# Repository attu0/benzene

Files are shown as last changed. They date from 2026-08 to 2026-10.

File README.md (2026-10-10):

<div align="center">

# 🤖 Benzene
### An Autonomous Differential-Drive Mobile Robot

**A ROS 2-based autonomous mobile robot developed at Rajarambapu Institute of Technology (RIT), with support from Taikisha Engineering India Ltd.**

Benzene Autonomous Mobile Robot

<p>
  <a href="https://github.com/attu0/benzene">📦 GitHub Repository</a> •
  <a href="https://drive.google.com/file/d/1qdtDz3HJxDPnA_4TYmKJY9449RnS3Dy-/view?usp=sharing">🎥 Robot Demonstration</a>
</p>

</div>

---

## 📌 Table of Contents

- [🤖 About the Project](#-about-the-project)
- [✨ Key Features](#-key-features)
- [🛠️ CAD Design and Physical Robot](#️-cad-design-and-physical-robot)
- [🏗️ System Architecture](#️-system-architecture)
- [🔌 Hardware Components](#-hardware-components)
- [📐 Circuit and Deployment Diagrams](#-circuit-and-deployment-diagrams)
- [💻 Software Stack](#-software-stack)
- [📦 ROS 2 Packages](#-ros-2-packages)
- [⚙️ Installation and Setup](#️-installation-and-setup)
- [🔨 Build the Workspace](#-build-the-workspace)
- [🌎 Run the Simulation](#-run-the-simulation)
- [🗺️ SLAM and Autonomous Navigation](#️-slam-and-autonomous-navigation)
- [🤖 Run on the Physical Robot](#-run-on-the-physical-robot)
- [📁 Repository Structure](#-repository-structure)
- [🚀 Future Improvements](#-future-improvements)
- [👥 Team and Acknowledgements](#-team-and-acknowledgements)
- [🤝 Contributing](#-contributing)
- [📄 License](#-license)

---

## 🤖 About the Project

**Benzene** is an autonomous differential-drive mobile robot developed as a final-year engineering project at **Rajarambapu Institute of Technology (RIT), Rajaramnagar**, with support from **Taikisha Engineering India Ltd.**

The project combines mechanical design, embedded systems, sensor integration, and robotics software to develop a mobile platform capable of navigating its environment.

The software architecture uses ROS 2 to connect robot hardware, sensor drivers, motion control, localisation, mapping, and navigation components. Gazebo and RViz2 support simulation, visualisation, and testing during development.

### 📋 Project Overview

| Specification | Details |
|---|---|
| **Robot Type** | Differential-drive mobile robot |
| **Robotics Middleware** | ROS 2 Jazzy |
| **Operating System** | Ubuntu 24.04 LTS |
| **Robot Modelling** | URDF / Xacro |
| **Simulation** | Gazebo |
| **Visualisation** | RViz2 |
| **Mapping** | SLAM Toolbox |
| **Navigation** | Nav2 |
| **Repository** | [attu0/benzene](https://github.com/attu0/benzene) |

---

## ✨ Key Features

- **Differential-Drive Control** — Independent left and right wheel control for forward, reverse, and turning motion.
- **ROS 2 Architecture** — Modular packages for robot description, control, hardware, sensors, and navigation.
- **Robot Modelling** — URDF/Xacro-based robot description for visualisation and simulation.
- **Gazebo Simulation** — Test robot behaviour in virtual environments.
- **SLAM** — Map an environment while estimating the robot's position.
- **Autonomous Navigation** — Nav2-based path planning and goal-directed navigation.
- **Sensor Integration** — Interfaces for LiDAR, IMU, camera, and ultrasonic sensing, depending on the active configuration.
- **Hardware Integration** — Communication between the onboard computer, embedded controller, and drive system.

> **Note:** Feature availability depends on the hardware, packages, launch files, and configuration in the current repository branch.

---

## 🛠️ CAD Design and Physical Robot

The robot chassis was designed to provide a compact platform for the drive system, onboard computer, sensors, and power electronics.

### 🧩 CAD Model

<p align="center">
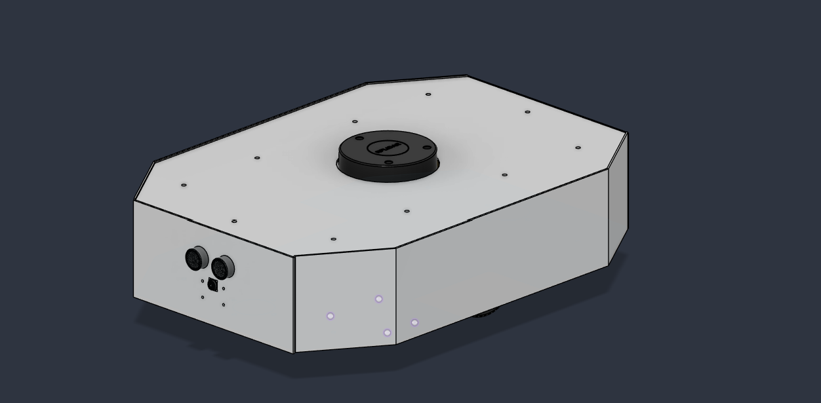
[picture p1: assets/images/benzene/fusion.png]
Benzene CAD model designed in Fusion 360
  
</p>

<p align="center"><em>CAD model of the Benzene mobile robot.</em></p>

### 🤖 Physical Prototype

<p align="center">
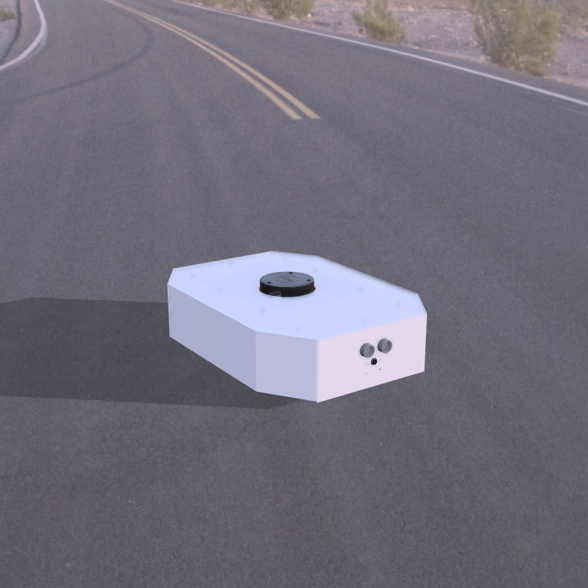
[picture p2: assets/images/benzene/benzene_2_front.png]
Benzene robot render
  
</p>

<p align="center"><em>Rendered view of the Benzene mobile robot.</em></p>

🎥 **[Watch the Robot Demonstration](https://drive.google.com/file/d/1qdtDz3HJxDPnA_4TYmKJY9449RnS3Dy-/view?usp=sharing)**

---

## 🏗️ System Architecture

The system architecture connects the sensing, control, localisation, and navigation components through ROS 2.

```text
                 ┌───────────────────────────┐
                 │         ROS 2 Jazzy       │
                 │    Robotics Middleware    │
                 └─────────────┬─────────────┘
                               │
              ┌────────────────┼────────────────┐
              │                │                │
              ▼                ▼                ▼
       ┌─────────────┐  ┌─────────────┐  ┌─────────────┐
       │   Control   │  │ Localisation│  │ Navigation  │
       │ Motor Cmds  │  │  Odometry   │  │    Nav2     │
       └──────┬──────┘  └──────▲──────┘  └──────┬──────┘
              │                │                │
              ▼                │                ▼
       ┌─────────────────────────────────────────────┐
       │                Robot Hardware               │
       │ Motors │ Encoders │ IMU │ LiDAR │ Sensors  │
       └─────────────────────────────────────────────┘
```

### Operating Modes

| Mode | Description |
|---|---|
| **Simulation** | Robot model and simulated environment run in Gazebo. |
| **Physical Robot** | ROS 2 communicates with the robot hardware through the configured hardware interfaces. |

> The architecture is a conceptual overview. Actual nodes, topics, transforms, and interfaces depend on the launch configuration.

---

## 🔌 Hardware Components

The robot integrates mechanical, electrical, and computing components to support mobile robotics development.

| Subsystem | Component |
|---|---|
| Mobile Base | Differential-drive chassis |
| Main Computer | Raspberry Pi |
| Microcontroller | Arduino Uno R3 |
| Drive System | Geared DC motors |
| Motor Control | Dual-channel motor driver |
| Feedback | Wheel encoders, where configured |
| Range Sensing | 2D LiDAR |
| Inertial Sensing | IMU |
| Proximity Sensing | Ultrasonic sensor |
| Power System | Battery and regulated DC supply |
| Mechanical Structure | Designed and fabricated chassis |

*Verify the actual component models, pin assignments, and electrical connections against the current hardware revision before assembly or operation.*

---

## 📐 Circuit and Deployment Diagrams

### 🔋 Electrical Circuit Diagram

<p align="center">
  Benzene electrical circuit and wiring diagram
</p>

The circuit diagram illustrates the electrical connections between the power supply, voltage regulation, motor driver, microcontroller, onboard computer, and sensors.

### 🖥️ Hardware Deployment Diagram

<p align="center">
  Benzene hardware deployment diagram
</p>

The deployment diagram provides a view of the robot's internal hardware layout and component placement.

---

## 💻 Software Stack

| Technology | Purpose |
|---|---|
| **ROS 2 Jazzy** | Robotics middleware |
| **Ubuntu 24.04 LTS** | Development operating system |
| **URDF / Xacro** | Robot description |
| **Gazebo** | Simulation |
| **RViz2** | Robot and sensor visualisation |
| **ros2_control** | Hardware and motion control, where configured |
| **EKF** | Sensor fusion and state estimation, where configured |
| **SLAM Toolbox** | Mapping |
| **Nav2** | Autonomous navigation |
| **colcon** | Workspace build system |
| **rosdep** | Dependency management |

---

## 📦 ROS 2 Packages

The repository follows a modular package structure.

| Package | Purpose |
|---|---|
| `benzene_arduino` | Embedded controller code and hardware testing |
| `benzene_bringup` | Robot launch files and startup configuration |
| `benzene_camera` | Camera integration |
| `benzene_control` | Controller configuration |
| `benzene_dagger` | Behavioural cloning and imitation learning |
| `benzene_description` | URDF/Xacro and robot model resources |
| `benzene_docking` | Docking-related functionality |
| `benzene_explore` | Autonomous exploration |
| `benzene_explore_msgs` | Exploration-related interfaces |
| `benzene_gazebo` | Simulation worlds, models, and launch files |
| `benzene_hardware` | Hardware interfaces |
| `benzene_imu` | IMU integration |
| `benzene_localization` | Localisation and sensor fusion |
| `benzene_msgs` | Custom ROS 2 interfaces |
| `benzene_navigation` | SLAM, Nav2, maps, and navigation configuration |
| `benzene_serial` | Serial communication |
| `benzene_system_tests` | System-level testing |
| `benzene_ultrasonic` | Ultrasonic sensor integration |
| `docker` | Docker configuration |

---

## ⚙️ Installation and Setup

### Requirements

**Software**
- Ubuntu 24.04 LTS
- ROS 2 Jazzy
- Git
- `colcon`
- `rosdep`
- Gazebo and RViz2
- Nav2 and SLAM Toolbox for the configured navigation workflow

### 1. Create a Colcon Workspace

```bash
mkdir -p ~/ros2_ws/src
cd ~/ros2_ws/src
```

### 2. Clone the Repository

```bash
git clone https://github.com/attu0/benzene.git
cd benzene
```

### 3. Install Build and Dependency Tools

Install ROS 2 Jazzy by following the [official installation guide](https://docs.ros.org/en/jazzy/Installation/Ubuntu-Install-Debs.html).

```bash
sudo apt update
sudo apt install python3-rosdep python3-colcon-common-extensions
```

Initialise `rosdep` if it has not already been initialised:

```bash
sudo rosdep init
rosdep update
```

If `rosdep` is already initialised, run only:

```bash
rosdep update
```

### 4. Install Repository Dependencies

```bash
cd ~/ros2_ws
source /opt/ros/jazzy/setup.bash

rosdep install \
  --from-paths src \
  --ignore-src \
  --rosdistro jazzy \
  -r -y
```

---

## 🔨 Build the Workspace

Navigate to the workspace root and build the packages:

```bash
cd ~/ros2_ws
source /opt/ros/jazzy/setup.bash
colcon build --symlink-install
```

To build a specific package and its dependencies:

```bash
colcon build --symlink-install --packages-up-to benzene_bringup
```

### Source the Workspace

After a successful build:

```bash
source ~/ros2_ws/install/setup.bash
```

### Automatically Source ROS 2 Using `.bashrc`

To automatically source ROS 2 and your workspace in new terminals, add the following lines to `~/.bashrc`:

```bash
# ROS 2 Jazzy
source /opt/ros/jazzy/setup.bash

# Benzene workspace
source ~/ros2_ws/install/setup.bash
```

Reload the configuration:

```bash
source ~/.bashrc
```

Verify that the packages are discoverable:

```bash
ros2 pkg list | grep benzene
```

---

## 🌎 Run the Simulation

Benzene includes Gazebo simulation resources for testing the robot in virtual environments.

### 1. Source the Environment

```bash
source /opt/ros/jazzy/setup.bash
source ~/ros2_ws/install/setup.bash
```

### 2. Launch Gazebo

The following example launches the robot in a warehouse environment:

```bash
ros2 launch benzene_gazebo benzene.gazebo.launch.py \
  enable_odom_tf:=true \
  headless:=False \
  load_controllers:=true \
  world_file:=warehouse.sdf \
  use_rviz:=true \
  use_robot_state_pub:=true \
  use_sim_time:=true \
  x:=0.0 y:=0.0 z:=0.20 \
  roll:=0.0 pitch:=0.0 yaw:=0.0
```

> **Note:** Launch arguments and world filenames may vary between branches. Check the launch file's supported arguments if the command does not match your current setup.

---

## 🗺️ SLAM and Autonomous Navigation

Benzene uses **SLAM Toolbox** and **Nav2** in the configured mapping and navigation workflow.

### Launch Navigation in Simulation

```bash
ros2 launch benzene_bringup benzene_navigation.launch.py \
  enable_odom_tf:=false \
  headless:=False \
  load_controllers:=true \
  slam:=True \
  use_rviz:=true \
  use_robot_state_pub:=true \
  use_sim_time:=true \
  x:=0.0 y:=0.0 z:=0.20 \
  roll:=0.0 pitch:=0.0 yaw:=0.0 \
  world_file:=cafe.world \
  sim:=true
```

> **Note:** Confirm that the launch file supports these arguments and that the specified world file exists in your branch.

### 🗺️ Create a Map

1. Start the simulation or bring up the physical robot.
2. Verify that LiDAR data is being published.
3. Check odometry and the TF tree.
4. Start SLAM Toolbox using the available launch configuration.
5. Move the robot through the environment.
6. Monitor the map in RViz2.
7. Save the map.

```bash
ros2 run nav2_map_server map_saver_cli -f ~/benzene_map
```

The command saves the map to files such as `benzene_map.yaml` and `benzene_map.pgm`.

### 🎯 Navigate Using a Saved Map

Configure the navigation stack to load the saved map and start localisation. In RViz2, set the initial pose when required, send a navigation goal, and monitor the robot's progress.

---

## 🖥️ Helper Scripts

The repository includes helper scripts for common launch workflows.

### Make the Scripts Executable

```bash
chmod +x ~/ros2_ws/src/benzene/benzene_bringup/scripts/*
```

### Launch Gazebo

```bash
~/ros2_ws/src/benzene/benzene_bringup/scripts/benzene_gazebo.sh
```

### Launch Navigation

```bash
~/ros2_ws/src/benzene/benzene_bringup/scripts/benzene_navigation.sh
```

Check the scripts for supported arguments before passing optional parameters.

---

## 🤖 Run on the Physical Robot

Before enabling autonomous navigation, verify the electrical system, motor control, sensor data, and ROS 2 communication.

1. Secure the robot and keep the drive wheels clear of the floor during initial motor tests.
2. Check battery voltage, regulator output, polarity, and common ground.
3. Verify the embedded firmware and motor-driver wiring.
4. Configure the serial device and communication parameters.
5. Start the hardware interface and sensor drivers.
6. Verify odometry, IMU data, LiDAR data, and TF transforms.
7. Start localisation and navigation after confirming the data is valid.
8. Test at low speed in a clear area.

### 🔍 Diagnostic Commands

```bash
ros2 topic list
ros2 topic info /cmd_vel
ros2 topic echo /odom
ros2 topic echo /imu/data
ros2 topic echo /scan
```

> ⚠️ **Safety:** Verify motor direction, emergency-stop behaviour, wiring polarity, regulator voltage, and motor-driver current limits before operating the robot. Keep hands, clothing, and loose cables away from moving parts.

---

## 📁 Repository Structure

```text
benzene/
├── assets/
│   └── images/
│       └── benzene/
│           ├── fusion.png
│           ├── benzene_final.jpeg
│           ├── benzene_2_front.png
│           ├── circuit.jpeg
│           └── benzene_top.jpeg
├── benzene_arduino/
├── benzene_bringup/
│   ├── launch/
│   └── scripts/
├── benzene_camera/
├── benzene_control/
├── benzene_dagger/
├── benzene_description/
├── benzene_docking/
├── benzene_explore/
├── benzene_explore_msgs/
├── benzene_gazebo/
│   ├── launch/
│   ├── models/
│   └── worlds/
├── benzene_hardware/
├── benzene_imu/
├── benzene_localization/
├── benzene_msgs/
├── benzene_navigation/
│   ├── config/
│   ├── launch/
│   └── maps/
├── benzene_serial/
├── benzene_system_tests/
├── benzene_ultrasonic/
├── docker/
└── README.md
```

---

## 🚀 Future Improvements

Potential areas for continued development include:

- Improving wheel odometry and sensor-fusion accuracy.
- Developing more robust autonomous exploration.
- Improving obstacle detection and avoidance.
- Adding camera-based perception and visual navigation.
- Integrating battery monitoring and power management.
- Developing automated docking and charging.
- Extending imitation learning and behavioural cloning.
- Exploring DAgger-based data collection and policy improvement.
- Expanding simulation testing and hardware validation.

---

## 👥 Team and Acknowledgements

Developed as a final-year B.Tech Mechatronics Engineering capstone project at **Rajarambapu Institute of Technology (RIT), Rajaramnagar**, with support from **Taikisha Engineering India Ltd.**

| Team Member |
|---|
| Atharv Mahesh Mudse |
| Riddhi Anirudha Wagh |
| Abhay Ajit Potdar |
| Tushar Kailas Jadhav |

**Project Guide:** Prof. Shital A. Lavte

We acknowledge the support and guidance that helped us develop the mechanical prototype and robotics software.

---

## 🤝 Contributing

Contributions, bug reports, and suggestions are welcome.

1. Fork the repository.
2. Create a feature branch.
3. Implement and test your changes.
4. Build the affected ROS 2 packages.
5. Submit a pull request describing your changes.

```bash
git clone https://github.com/attu0/benzene.git
cd benzene
git checkout -b feature/your-feature
```

---

## 📄 License

Refer to the [`LICENSE`](./LICENSE) file for the project's licensing terms.

---

<div align="center">

### 🤖 Benzene — Autonomous Mobile Robotics

**ROS 2 · SLAM · Nav2 · Gazebo · Embedded Systems**

[📦 GitHub Repository](https://github.com/attu0/benzene) • [🎥 Robot Demonstration](https://drive.google.com/file/d/1qdtDz3HJxDPnA_4TYmKJY9449RnS3Dy-/view?usp=sharing)

</div>

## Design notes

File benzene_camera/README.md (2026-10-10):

# Benzene Camera

## Overview

The `benzene_camera` package provides a ROS 2 camera node based on **libcamera**. It supports compatible V4L2 cameras and Raspberry Pi camera modules.

The node captures images and publishes them as ROS 2 image messages. It also publishes camera calibration information and provides a service for updating camera parameters.

## Features

- Camera support through libcamera
- Raw and compressed image topics
- Camera information publishing
- Runtime camera control parameters
- Camera orientation and resolution configuration
- Camera calibration support
- Integration with the ROS 2 image pipeline

## Requirements

- ROS 2 Jazzy
- A camera supported by the installed libcamera version
- libcamera version 0.1 or later
- Required ROS 2 dependencies, including sensor message interfaces

**Note:** Raspberry Pi camera support depends on the installed libcamera version. Some newer camera modules may require the Raspberry Pi libcamera fork.

## Installation

Source ROS 2:

```bash
source /opt/ros/jazzy/setup.bash
```

Install the available ROS camera package if it is provided for your distribution:

```bash
sudo apt update
sudo apt install ros-jazzy-camera-ros
```

For a source build, make sure the `benzene_camera` package and its dependencies are present in the workspace. Install dependencies and build:

```bash
cd ~/benzene
rosdep install --from-paths . --ignore-src -r -y
colcon build --packages-up-to benzene_camera --symlink-install
source install/setup.bash
```

If the workspace uses a custom libcamera installation, follow the corresponding dependency instructions and avoid mixing incompatible system and source installations.

## Running the Camera Node

Run the standalone camera node:

```bash
ros2 run benzene_camera camera_node
```

Launch the composable node using the provided launch file:

```bash
ros2 launch benzene_camera camera.launch.py
```

The launch command requires the corresponding launch file to be included and installed by the package.

## ROS 2 Interfaces

### Topics

| Topic | Message type | Description |
|---|---|---|
| `~/image_raw` | `sensor_msgs/msg/Image` | Raw camera images |
| `~/image_raw/compressed` | `sensor_msgs/msg/CompressedImage` | Compressed camera images |
| `~/camera_info` | `sensor_msgs/msg/CameraInfo` | Camera calibration and intrinsic parameters |

The `~` prefix denotes a node-private topic. The fully resolved topic name depends on the node name and namespace.

### Services

| Service | Type | Description |
|---|---|---|
| `~/set_camera_info` | `sensor_msgs/srv/SetCameraInfo` | Update camera calibration information |

## Camera Configuration

The camera stream is configured when the node starts.

| Parameter | Description |
|---|---|
| `camera` | Camera index or camera name |
| `role` | Stream role, such as `raw`, `still`, `video`, or `viewfinder` |
| `format` | Requested pixel format |
| `width` | Desired image width |
| `height` | Desired image height |
| `sensor_mode` | Desired raw sensor resolution in `width:height` format |
| `orientation` | Camera orientation: 0, 90, 180, or 270 degrees |
| `camera_info_url` | URL of the camera calibration file |
| `frame_id` | Frame identifier in the image message header |
| `use_node_time` | Whether to use node time instead of the sensor timestamp |

Available formats and supported resolutions depend on the camera hardware and libcamera implementation.

### Setting Parameters

Parameters can be passed when starting the node. For example:

```bash
ros2 run benzene_camera camera_node --ros-args \
  -p width:=640 \
  -p height:=480
```

For a fixed frame duration of 50,000 microseconds, equivalent to 20 Hz, if the camera exposes `FrameDurationLimits`:

```bash
ros2 run benzene_camera camera_node --ros-args \
  -p 'FrameDurationLimits:=[50000,50000]'
```

Check the actual supported parameters for your installed version before using camera-specific controls.

## Camera Calibration

The node uses a camera information manager to load and publish calibration parameters, including camera intrinsics and distortion coefficients.

The `camera_info_url` parameter specifies the calibration file. Its default location is typically:

```text
~/.ros/camera_info/$NAME.yaml
```

When providing a custom calibration file, use a file URL, for example:

```text
file:///home/user/camera/calibration.yaml
```

A calibration file can be generated using the ROS 2 `camera_calibration` package. Without calibration data, the node may publish zero-initialized camera parameters.

## Troubleshooting

| Problem | Suggested action |
|---|---|
| No camera detected | Check the camera connection and whether libcamera recognizes the device |
| Camera node fails to start | Check the installed dependencies and terminal logs |
| Requested resolution is unavailable | Use a resolution and pixel format supported by the camera |
| Image buffers cannot be allocated | Reduce resolution or select a lower-memory pixel format |
| Calibration

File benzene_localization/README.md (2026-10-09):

this is about amcl and localization using kalman filter and ekf

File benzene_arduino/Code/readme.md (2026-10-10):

# Benzene Uno Firmware (PlatformIO)

Real-time base controller for the Benzene differential-drive robot.

The Arduino Uno handles wheel encoders, velocity PID control, and the L298N motor driver. The IMU and ultrasonic sensors are handled by the Raspberry Pi.

## Features

- Quadrature encoder decoding for both wheels
- Closed-loop wheel velocity control using PID
- L298N motor driver control
- Binary serial protocol with CRC8
- Typed serial commands for testing and debugging
- 50 Hz control loop
- Watchdog timeout to stop the motors when commands are no longer received

## Project Structure

| File | Purpose | Modify when |
|---|---|---|
| `include/config.h` | Pin assignments, direction signs, PID defaults, and timing | Rewiring, changing motor direction, or tuning PID |
| `src/encoders.cpp` | Quadrature decoding using two pin-change interrupt service routines | Changing encoder pins or decoding logic |
| `src/motors.cpp` | L298N PWM and direction control | Changing the motor driver |
| `src/pid.cpp` | Per-wheel velocity controller | Changing the control algorithm |
| `src/protocol.cpp` | Binary framing, CRC8, text-line parsing, and STATE messages | Adding or modifying protocol messages |
| `src/console.cpp` | Typed serial commands | Adding a diagnostic or test command |
| `src/main.cpp` | Main program, 50 Hz control loop, and watchdog | Adding new firmware behaviour |

The wire protocol is documented at the top of `include/protocol.h`.

## Requirements

- Arduino Uno
- L298N motor driver
- Two DC motors with quadrature encoders
- USB connection between the Uno and host computer
- PlatformIO Core or the PlatformIO extension for VS Code
- Python and `pyserial` for hardware bring-up tests

## Build and Upload

Run these commands from the firmware directory containing `platformio.ini`:

```bash
pio run
pio run --target upload
```

If multiple serial devices are connected, configure the correct upload port in the PlatformIO configuration before uploading.

## Wiring

### Wheel encoders

| Signal | Uno pin |
|---|---|
| Left encoder A | D2 |
| Left encoder B | D3 |
| Right encoder A | A4 |
| Right encoder B | A5 |
| Encoder VCC | 5V |
| Encoder GND | GND |

### L298N motor driver

| Signal | Uno pin |
|---|---|
| Left motor IN forward | D10 |
| Left motor IN backward | D6 |
| Left motor EN | D13 |
| Right motor IN forward | D9 |
| Right motor IN backward | D5 |
| Right motor EN | D12 |

The two EN pins are held HIGH. Motor outputs are not driven until the first non-zero motor command.

**Power and safety notes:**

- The Uno is powered over USB.
- Connect the battery negative, L298N GND, and Uno GND together.
- Keep the wheels off the ground during initial testing.
- Verify the actual pin assignments in `include/config.h` before wiring. If using an alternative wiring diagram, follow the configuration defined in the firmware.

## Testing and Bring-Up

The `tools/benzene_test.py` script is the hardware bring-up tool.

Install its Python dependency:

```bash
python3 -m pip install pyserial
```

Run the script's built-in help to check the supported command syntax:

```bash
python3 tools/benzene_test.py --help
```

The bring-up sequence is:

1. `listen` — check serial communication.
2. `ticks` — verify encoder tick reporting.
3. `cpr` — check counts per revolution.
4. `spin` — verify wheel direction and encoder signs.
5. `step` — test velocity response.
6. `watchdog` — verify the timeout behaviour.

Run tests with the wheels off the ground. The test tool aborts and stops the motors if an encoder sign is incorrect.

## Typed Serial Commands

The firmware supports one typed command per line. The `?` command lists available commands.

| Command | Purpose | Reply |
|---|---|---|
| `e` | Read encoder ticks | `left right` |
| `v` | Read measured wheel speeds in ticks/s | `left right` |
| `r` | Reset encoder counters | `OK` |
| `d <w> <c>` | Read a raw encoder pin (`w`: 0 = left, 1 = right; `c`: 0 = C1, 1 = C2) | `0` or `1` |
| `m <l> <r>` | Set closed-loop speed targets in ticks/s | `OK` |
| `o <l> <r>` | Set open-loop PWM from -255 to 255; bypasses PID | `OK` |
| `u kp ki kd [kff]` | Set PID gains | `OK` |

### Safety behaviour

- Motors stop two seconds after the last `m` or `o` command.
- The binary STATE stream remains disabled until the firmware receives its first binary frame.
- Sending a typed text command disables the binary STATE stream again, keeping serial-monitor output readable.

**Serial monitor note:** Do not use `pio device monitor` while another program owns the serial port. Only one program can use the port at a time. Close the monitor before running the Python bring-up tool or another serial client.

## Adding a New Protocol Message

1. Add the message type constant and callback declaration in `include/protocol.h`.
2. Implement message parsing and dispatch in `src/protocol.cpp`.
3. Connect the callback in `src/main.cpp`.
4. Update the protocol documentation and test the new message with the host software.

## Troubleshooting

| Problem | What to check |
|---|---|
| Upload fails | USB connection, selected upload port, and PlatformIO configuration |
| No encoder ticks | Encoder power, common ground, signal wiring, and pin assignments |
| Wheel moves in the wrong direction | Motor wiring and direction signs in `include/config.h` |
| Encoder counts decrease unexpectedly | Encoder A/B wiring and encoder direction configuration |
| Motors stop unexpectedly | Host command frequency and the two-second watchdog timeout |
| Serial port is busy | Close other serial clients before running tests |
| PID response is poor | Verify encoder scaling and tune PID parameters carefully |

## Related Packages

- `benzene_serial` — host-side serial communication.
- `benzene_hardware` — hardware integration with ROS 2 control.
- `benzene_control` — robot motion control.

Refer to the main [Benzene README](../README.md) for workspace-level setup and integration instructions.

## License

See the repository's [LICENSE](../LICENSE) file.

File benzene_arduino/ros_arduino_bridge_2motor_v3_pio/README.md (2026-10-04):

# ROS Arduino Bridge - 2 Motor V4 (PlatformIO)

V3 rebuilt to match the serial protocol of
[joshnewans/ros_arduino_bridge](https://github.com/joshnewans/ros_arduino_bridge)
(a fork of hbrobotics/ros_arduino_bridge), so ROS-side drivers that speak that
protocol work with this robot. Your hardware settings from V3 are kept.

```text
pio run                  build
pio run -t upload        build + flash
pio device monitor       serial monitor (57600, CR line ending - preset)
```

## Serial protocol (same as upstream)

57600 baud. **Every command ends with a carriage return (CR, `\r`)**.

```text
e                  read encoders           -> "<left> <right>"
r                  reset encoders + PID    -> OK
o <L> <R>          raw PWM, -255..255      -> OK   (PID off)
m <L> <R>          closed-loop speed, in encoder COUNTS PER FRAME -> OK
u <Kp>:<Kd>:<Ki>:<Ko>   set PID gains      -> OK
b                  print baud rate
a/d <pin>          analogRead / digitalRead
c/w/x <pin> <val>  pinMode / digitalWrite / analogWrite     -> OK
p <pin>            ping (ultrasonic distance, cm)
```

- A frame is 1/30 s (30 Hz PID). 1 rev/s is about 1558/30 = 52 counts/frame.
- **Auto-stop:** motors stop if no `o` / `m` arrives for 2 s. Keep sending.
- `m 0 0` stops and resets the PID.
- Default PID gains are upstream's (`20:12:0:50`), tuned for a different
  robot. Expect to tune them with `u`.

### Moving from the V3 commands

| V3 | V4 |
|---|---|
| `f 100` | `o 100 100` |
| `b 100` | `o -100 -100` |
| `l 100` | `o -100 100` |
| `t 100` | `o 100 -100` |
| `s` / `0` / `x` | `o 0 0` (or `m 0 0`) |
| `h` | removed |
| `e` | `e` (now one line: `<left> <right>`) |
| `r` | `r` (now prints `OK`) |

`s`, `t`, `b`, `x` could not be kept: upstream uses those letters
for servo write, servo read, baud rate and analogWrite.

## Direction (unchanged from V3)

Positive PWM = shaft **clockwise** on both motors.

```text
o 100 100     both clockwise            (forward)
o -100 -100   both counter-clockwise    (backward)
o -100 100    LEFT ccw, RIGHT cw        (turn left)
o 100 -100    LEFT cw,  RIGHT ccw       (turn right)
```

## Pins

| Function | Pins |
|---|---|
| Right motor | EN 5 (PWM), FORWARD 9, BACKWARD 8 |
| Left motor | EN 6 (PWM), FORWARD 10, BACKWARD 11 |
| Right wheel encoder | D2 / D3 |
| Left wheel encoder | A4 / A5 |

Both encoders are read in pin-change interrupts (PCINT2 for D2/D3, PCINT1 for
A4/A5). In V3 the A4/A5 encoder was polled in `loop()`.

**LEFT / RIGHT now mean the physical wheel.** In V3 the "LEFT encoder"
was the D2/D3 connector, which measures the physical RIGHT motor. V4 follows
the wheel, so `e` prints `<left wheel> <right wheel>` as ROS expects.

## First power-up (wheels OFF the ground)

A closed loop with the wrong encoder sign is positive feedback: the wheel
runs to full PWM. Check signs before using `m`.

1. `o 80 0` then `e` twice. The **first** number must change. (If the second
   one changes, the connector mapping is the other way round: swap the
   `LEFT_ENC_*` / `RIGHT_ENC_*` pin defines in `include/encoder_driver.h` and
   the matching ISR bodies.)
2. The number must **increase**. If it decreases, set `LEFT_ENC_INVERT 1` in
   `include/config.h`.
3. Repeat with `o 0 80` for the right wheel (second number,
   `RIGHT_ENC_INVERT`).
4. `o 0 0`, then try `m 10 10` (about 0.19 rev/s) and finish with `m 0 0`.

## Encoder calibration (from V3)

Measured by connector, as printed by the V3 `e` command:

| Connector | 15 rev | 30 rev | Average |
|---|---:|---:|---:|
| A4 / A5 (left wheel) | 23388 | 46814 | 1559.83 ticks/rev |
| D2 / D3 (right wheel) | 23356 | 46762 | 1557.89 ticks/rev |

The firmware reports raw counts only. Put ticks/rev in the host-side
configuration (e.g. your ROS driver). Please double-check which connector each
number belongs to; V3 labelled them "RIGHT" and "LEFT" by connector name.

## Layout

```text
include/config.h           build options, baud, PID rate, encoder invert
include/commands.h         command letters
include/motor_driver.h     pins (your L298N wiring)
include/encoder_driver.h   pins + notes
include/diff_controller.h  PID (upstream, unchanged)
include/sensors.h          ping
src/main.cpp               command parser + main loop
src/motor_driver.cpp
src/encoder_driver.cpp
```

Not ported: upstream's servo module (its default pins 3/4 collide with your
D3 encoder input, and the robot has no servos).

## Credits / license

Protocol, PID and command parser: Patrick Goebel / James Nugen (HBRC) and
Josh Newans, BSD license. The notice is kept at the top of `src/main.cpp`.

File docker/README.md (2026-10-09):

# Benzene Docker

Docker setup for running the Benzene robot workspace (ROS 2 Jazzy, Gazebo Harmonic, Nav2, RViz2) on a Linux host.

## Contents

| File | Purpose |
|---|---|
| `Dockerfile` | Builds the image: ROS 2 Jazzy base, Gazebo, Nav2, ros2_control, robot_localization, then builds the workspace |
| `build.sh` | Builds the `benzene:latest` image and creates the shared folder on the host |
| `docker-compose.yml` | Runs the container with GUI, device and shared-folder access |
| `workspace.sh` | Runs during the image build: `rosdep install` and `colcon build --symlink-install` |
| `entrypoint.sh` | Runs on every container start: sets `ROS_DOMAIN_ID`, sources ROS and the workspace |
| `bash_aliases.txt` | Aliases appended to the container's `.bashrc` |

## Requirements

- Linux host with a display server (X11)
- Docker Engine with the Compose plugin
- Roughly 20 GB of free disk space (the image is about 8 GB on disk, and the build needs extra for layers)

## Build

```bash
cd ~/ros2_ws/src/benzene/docker
./build.sh
```

The first build takes a while (about 15 to 25 minutes) because of the apt and ROS package installs. Later builds reuse cached layers.

For a completely fresh build with no cache:

```bash
./build.sh --no-cache
```

## Run

```bash
cd ~/ros2_ws/src/benzene/docker
xhost +local:docker
docker compose up -d
docker exec -it benzene bash
```

- `xhost +local:docker` allows GUI apps (RViz, Gazebo) in the container to open windows on your display. Run it once per login session.
- `docker compose up -d` starts the container in the background.
- `docker exec -it benzene bash` opens a shell inside it. Open more terminals with the same command.

## Aliases inside the container

| Alias | What it does |
|---|---|
| `x3 [cafe\|office]` | Launches the Gazebo simulation (default world: warehouse) |
| `x3_nav [slam] [cafe\|office]` | Launches Gazebo with Nav2 (default world: warehouse). Add `slam` first to run SLAM instead of using a saved map |
| `build_ros2_ws` | Rebuilds the workspace (`colcon build --symlink-install`) and sources it |

Examples:

```bash
x3                 # warehouse world
x3 cafe            # cafe world
x3_nav office      # Nav2 with the office map
x3_nav slam cafe   # SLAM in the cafe world
```

## Stop and clean up

```bash
docker compose down                  # stop and remove the container
docker compose up -d --force-recreate   # recreate it (resets any edits made inside the container)
```

## Notes

- **Paths:** inside the container your home is `/root`, so the workspace is at `/root/ros2_ws`. The launch scripts use `$HOME` so they work both on the host and in the container.
- **Source code is copied into the image at build time.** Edits on the host do not appear in the container until you rebuild with `./build.sh`, or mount the source by adding this under `volumes` in `docker-compose.yml`:

  ```yaml
  - ${HOME}/ros2_ws/src/benzene:/root/ros2_ws/src/benzene
  ```

  Then recreate the container and run `build_ros2_ws` after changing packages.
- **Shared folder:** `~/atharv/shared/ros2` on the host is mounted at `/root/shared/ros2` in the container. It stores `ros_domain_id.txt` (default `0`), which sets `ROS_DOMAIN_ID`. Computers that should talk to each other need the same value.
- **Hardware access:** the container runs with `privileged: true`, `network_mode: host` and `/dev` mounted, so USB and serial devices (Arduino) and `/dev/i2c-*` (IMU) are visible if connected to the host.
- **Build context size:** `.dockerignore` in the repo root excludes `.git`, `build/`, `install/`, `log/`, virtualenvs, and rosbags. If the build context grows to several GB, check what is being copied.

## Troubleshooting

| Problem | Fix |
|---|---|
| `no space left on device` during build | Free disk space: `docker builder prune -f` and `docker image prune -f`. Check that `.dockerignore` excludes `.venv` and `build/`. |
| `Cannot locate rosdep definition for [...]` | A `package.xml` lists a dependency that is not a valid rosdep key. Fix or remove it. For `ament_python`, use `<build_type>` in `<export>` instead of a dependency. |
| GUI windows do not open | Run `xhost +local:docker` on the host and check that `echo $DISPLAY` is set. |
| Map or world not found | The container has an old copy of the scripts. Rebuild with `./build.sh` or mount the source folder. |
| Gazebo cannot find models | Check that `GZ_SIM_RESOURCE_PATH` in the launch scripts includes `benzene_gazebo/models`. |
| Edits to scripts disappear | The container was recreated. Make the edit on the host, then rebuild or mount the source. |

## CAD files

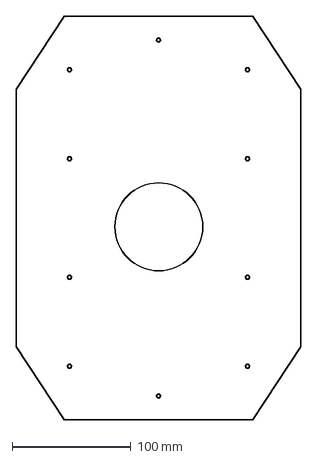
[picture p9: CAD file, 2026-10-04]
assets/laser_cut/upper.dxf
240.0 x 340.0 mm

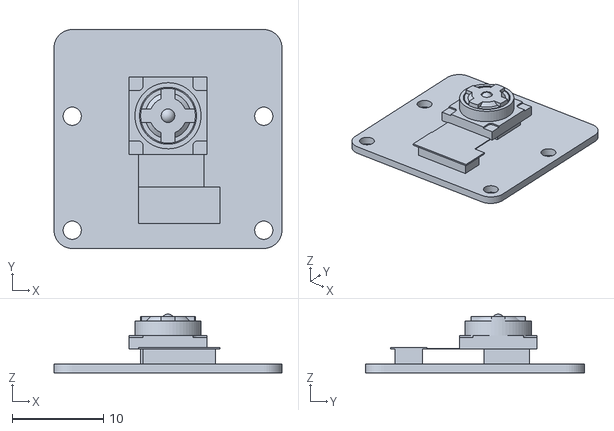
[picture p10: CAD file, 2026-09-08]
benzene_description/meshes/benzene/visual/camera_link.stl
25.0 x 24.0 x 6.45

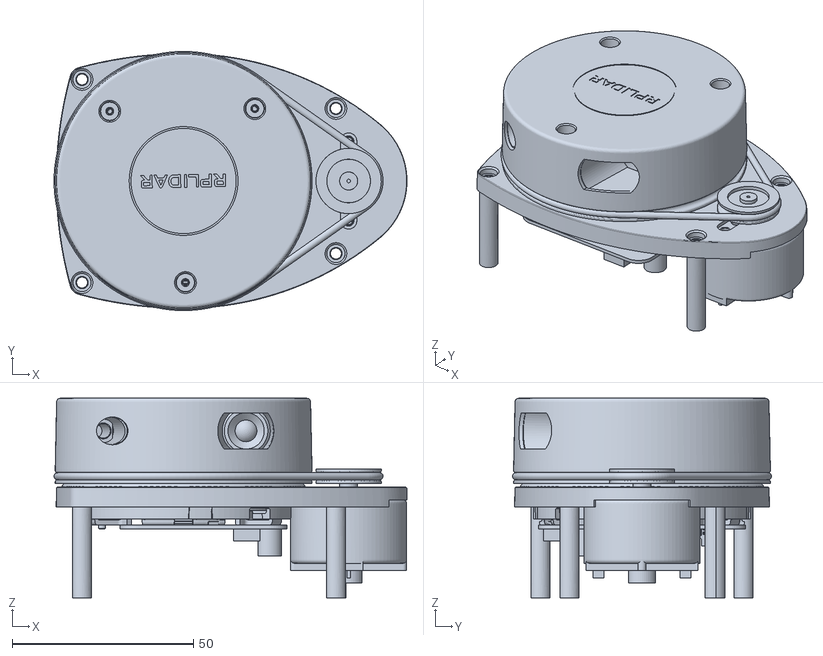
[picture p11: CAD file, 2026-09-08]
benzene_description/meshes/rplidar/rplidar_link.stl
97.3 x 71.4 x 55.0

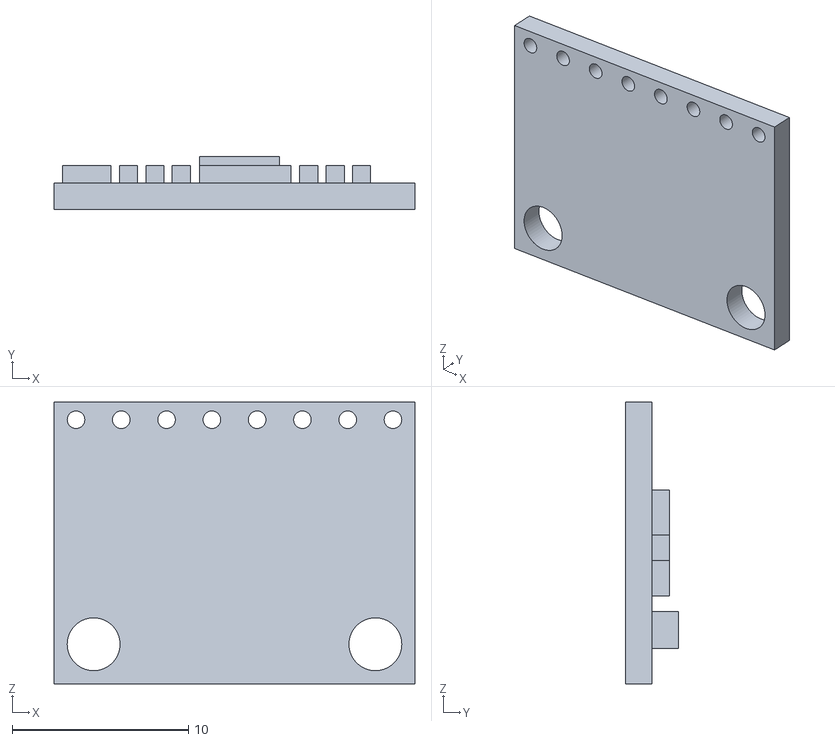
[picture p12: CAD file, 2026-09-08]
benzene_description/meshes/v3/visual/imu_link.stl
20.5 x 3.00 x 16.0

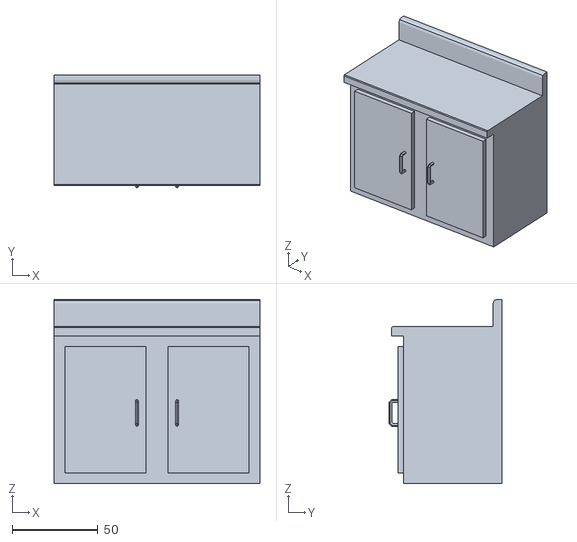
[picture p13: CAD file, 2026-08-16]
benzene_gazebo/models/cafe_counter/meshes/counter_no_sink.obj
120.0 x 65.8 x 107.3

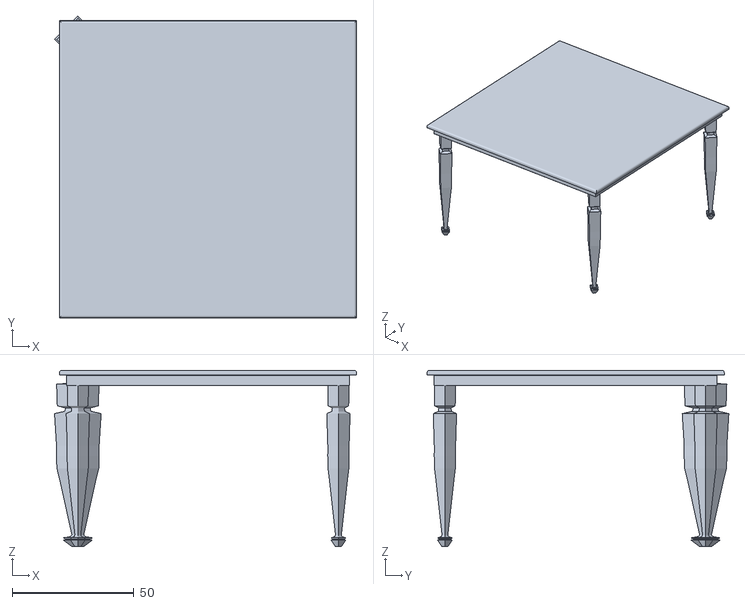
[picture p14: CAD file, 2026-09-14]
benzene_gazebo/models/ConferenceTable/meshes/conference_table.stl
124.0 x 123.9 x 72.5

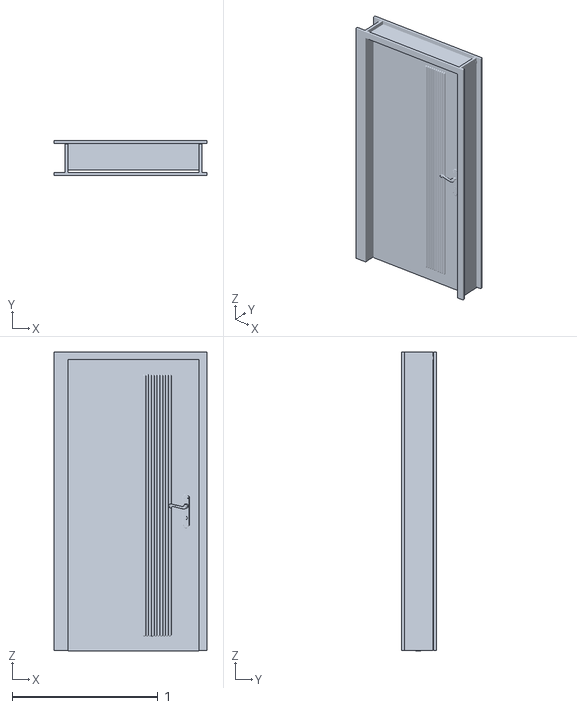
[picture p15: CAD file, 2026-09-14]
benzene_gazebo/models/Door/meshes/door.stl
1.05 x 0.241 x 2.05

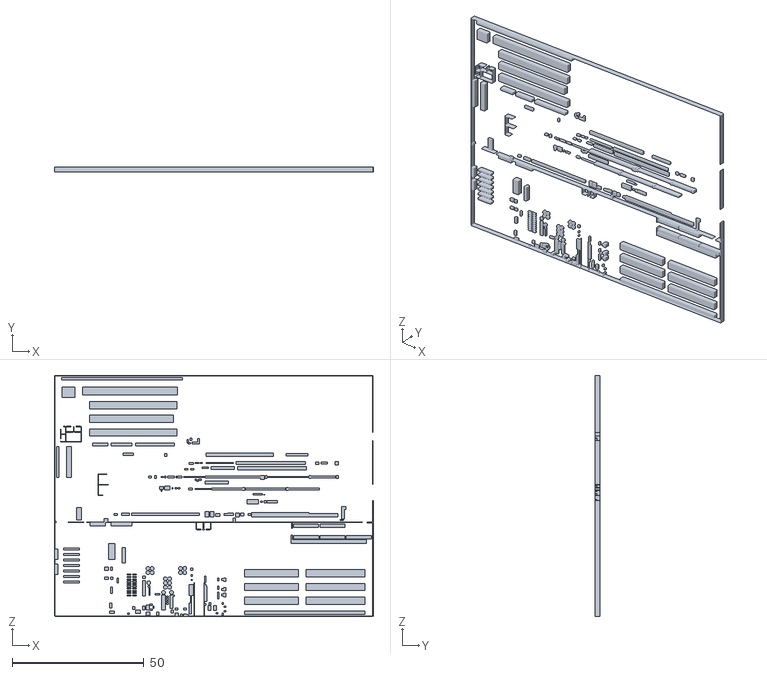
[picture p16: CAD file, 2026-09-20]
benzene_gazebo/models/emka_factory/meshes/emka_factory.stl
120.9 x 2.00 x 91.4

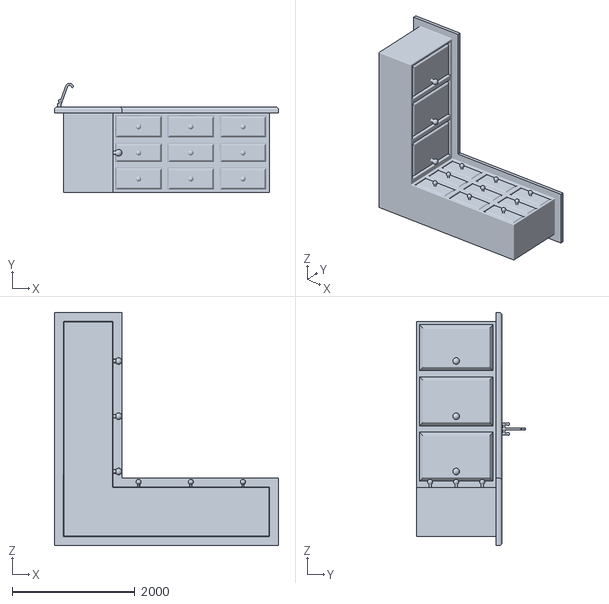
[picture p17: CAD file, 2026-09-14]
benzene_gazebo/models/Kitchen/meshes/kitchen.stl
3650.9 x 1782.5 x 3800.0

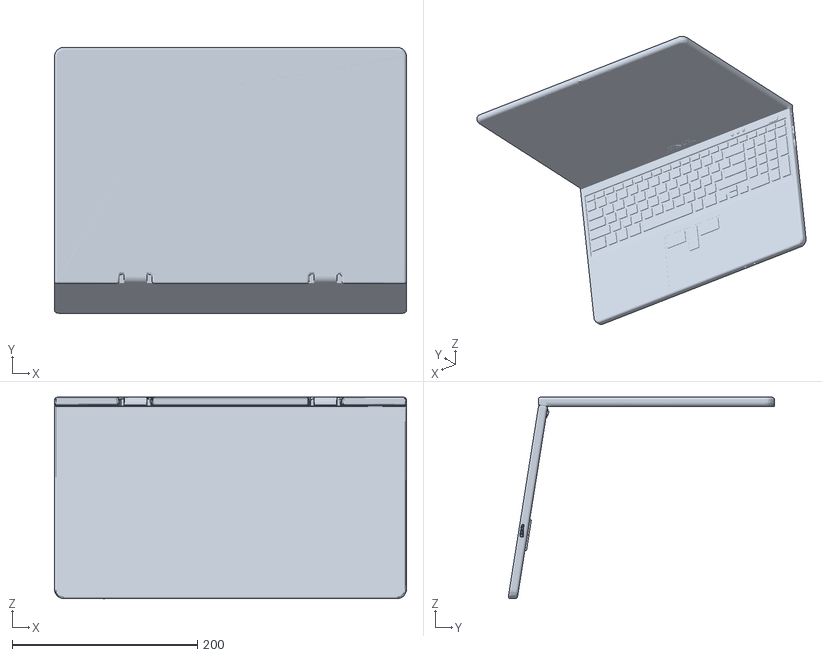
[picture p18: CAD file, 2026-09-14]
benzene_gazebo/models/Laptop/meshes/laptop.stl
380.0 x 287.5 x 217.7

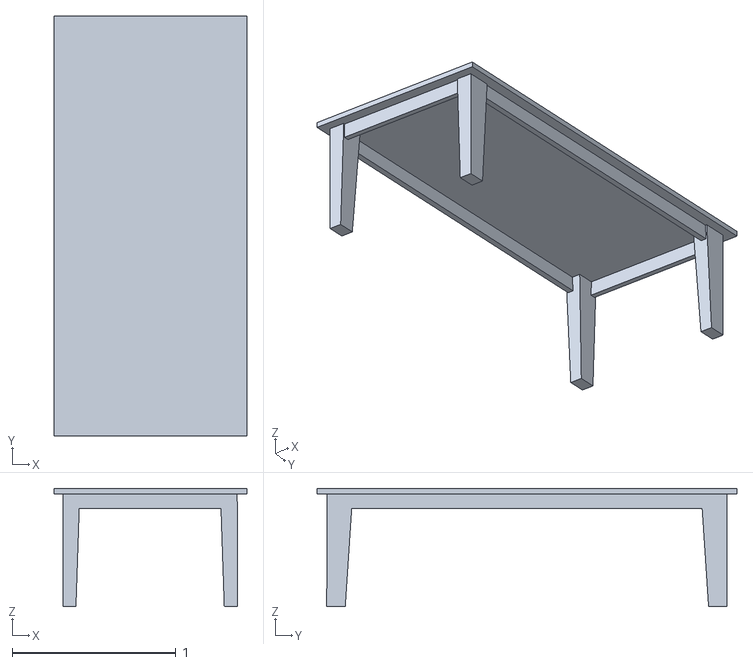
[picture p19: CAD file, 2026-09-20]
benzene_gazebo/models/office/meshes/ROB_long_table/ROB_long_table.stl
1.18 x 2.57 x 0.722

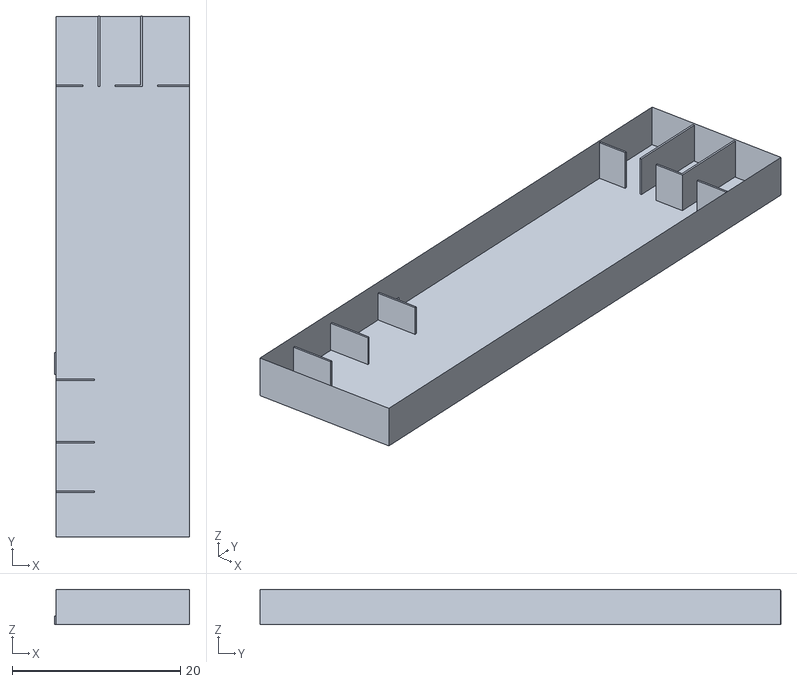
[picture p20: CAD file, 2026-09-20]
benzene_gazebo/models/office/meshes/ROB_office/ROB_office.stl
16.1 x 61.9 x 4.22

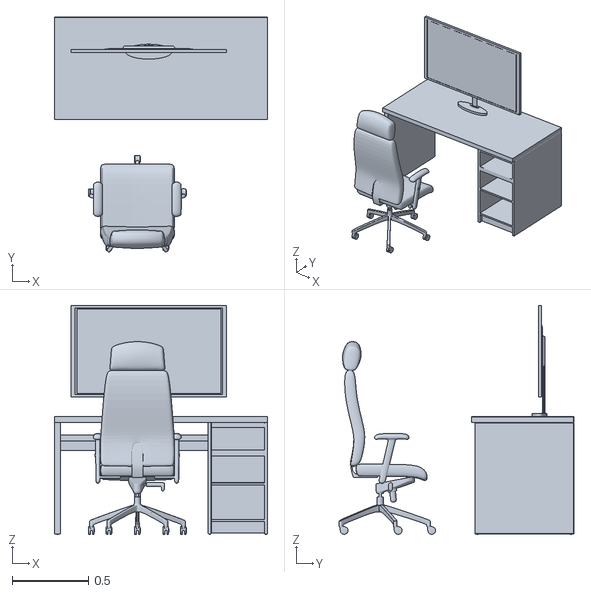
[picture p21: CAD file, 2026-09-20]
benzene_gazebo/models/office/meshes/ROB_work_station/ROB_work_station.stl
1.40 x 1.54 x 1.50

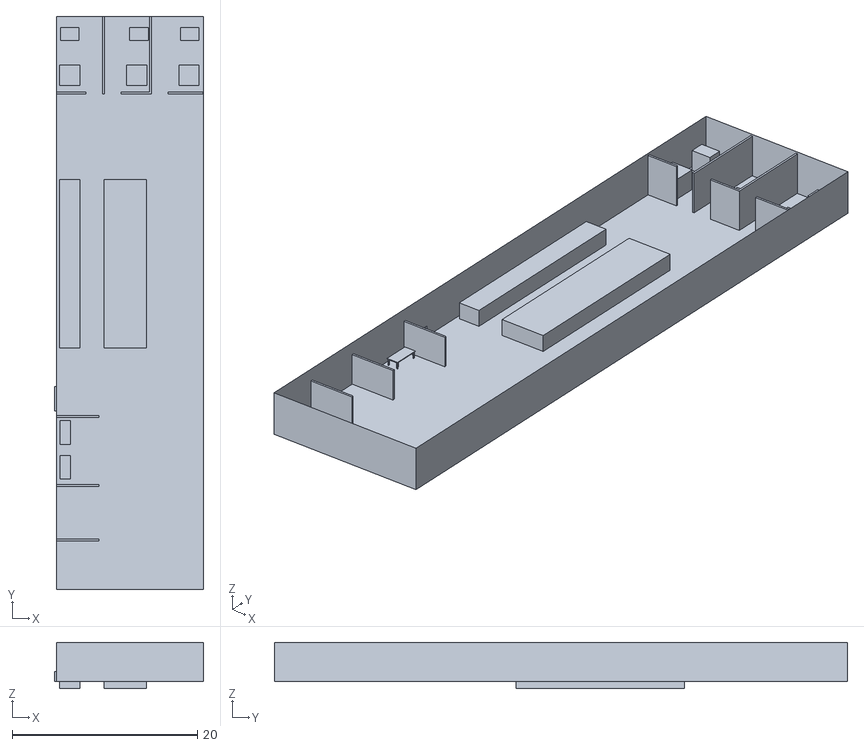
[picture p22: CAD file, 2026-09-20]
benzene_gazebo/models/office/meshes/test_collisions2.stl
16.1 x 61.9 x 5.00

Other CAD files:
benzene_gazebo/models/opil_warehouse/meshes/opil_warehouse.STL
benzene_gazebo/models/others/meshes/apple_collision.stl
benzene_gazebo/models/Surfaces/meshes/wall_1.obj
benzene_gazebo/models/Tv/meshes/tv.stl
assets/laser_cut/cross.dxf
assets/laser_cut/lower.dxf
assets/laser_cut/middle1.dxf
assets/laser_cut/middle2.dxf
assets/laser_cut/side.dxf
assets/laser_cut/switch.dxf
assets/laser_cut/uss.dxf
benzene_description/meshes/rplidar/lidar.stl
benzene_description/meshes/v3/visual/base_link.stl
benzene_description/meshes/v3/visual/camera.stl
benzene_description/meshes/v3/visual/caster_link.stl
benzene_description/meshes/v3/visual/chassis.stl
benzene_description/meshes/v3/visual/left_wheel.stl
benzene_description/meshes/v3/visual/right_wheel.stl
benzene_description/meshes/v3/visual/uss_link.stl
benzene_description/meshes/v3/visual/wheel_link.stl
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

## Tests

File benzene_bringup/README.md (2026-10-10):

# Benzene Bringup

## Overview

The `benzene_bringup` package provides launch files and scripts for starting and configuring the Benzene robot system using ROS 2.

It serves as an entry point for bringing up the robot's software components and coordinating their startup.

## Package Structure

| Directory | Purpose |
|---|---|
| `launch/` | ROS 2 launch files for starting robot components |
| `scripts/` | Helper scripts used during robot startup and operation |

## Requirements

- ROS 2 Jazzy
- The Benzene ROS 2 workspace
- Dependencies required by the selected launch file
- Hardware and device permissions when running with the physical robot

## Installation and Build

From the root of the workspace:

```bash
cd ~/benzene
source /opt/ros/jazzy/setup.bash
rosdep install --from-paths . --ignore-src -r -y
colcon build --symlink-install
source install/setup.bash
```

Run `rosdep install` from the appropriate workspace source directory if your workspace has a different layout.

## Usage

Source ROS 2 and the workspace before running launch files:

```bash
source /opt/ros/jazzy/setup.bash
source ~/benzene/install/setup.bash
```

List the available launch files:

```bash
ros2 pkg prefix benzene_bringup
```

Inspect the package's `launch/` directory to identify the supported launch files and their required arguments.

Launch the appropriate file using:

```bash
ros2 launch benzene_bringup <launch_file_name>
```

Replace `<launch_file_name>` with the actual launch filename, including the `.launch.py` extension.

## Helper Scripts

The `scripts/` directory contains supporting scripts for robot startup and operation.

Refer to each script's documentation and source code for its purpose, required arguments, and execution instructions.

## Troubleshooting

| Problem | Suggested action |
|---|---|
| Package not found | Source the ROS 2 installation and workspace setup files |
| Launch file not found | Check the filename and confirm that it is installed by the package |
| Missing dependencies | Run `rosdep install` and rebuild the workspace |
| Hardware access errors | Check device paths and Linux permissions |
| A node fails to start | Inspect its terminal output and verify its configuration |

## Related Packages

- `benzene_description` — robot description and model configuration.
- `benzene_hardware` — physical hardware integration.
- `benzene_control` — robot control functionality.
- `benzene_navigation` — navigation configuration and launch files.
- `benzene_gazebo` — simulation resources.

Refer to the main [Benzene README](../README.md) for overall project setup.

## License

See the repository's [LICENSE](../LICENSE) file.

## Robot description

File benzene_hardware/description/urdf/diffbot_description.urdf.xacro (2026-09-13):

<?xml version="1.0"?>
<robot xmlns:xacro="http://www.ros.org/wiki/xacro">

  <xacro:macro name="diffbot" params="prefix">

  <!-- Constants for robot dimensions -->
  <xacro:property name="PI" value="3.1415926535897931"/>
  <xacro:property name="base_mass" value="0.3" /> <!-- arbitrary value for base mass -->
  <xacro:property name="base_width" value="0.1" />
  <xacro:property name="base_length" value="0.1" />
  <xacro:property name="base_height" value="0.05" />
  <xacro:property name="wheel_mass" value="0.3" /> <!-- arbitrary value for wheel mass -->
  <xacro:property name="wheel_len" value="0.020" />
  <xacro:property name="wheel_radius" value="0.035" />
  <xacro:property name="caster_wheel_mass" value="0.1" /> <!-- arbitrary value for caster wheel mass -->
  <xacro:property name="caster_wheel_radius" value="0.015" />
  <xacro:property name="z_offset" value="-${base_height/2}" /> <!-- Space btw top of beam and the each joint -->

  <!-- Base Link -->
  <link name="${prefix}base_link">
    <collision>
      <origin xyz="0 0 0" rpy="0 0 0"/>
      <geometry>
        <box size="${base_width} ${base_length} ${base_height}"/>
      </geometry>
    </collision>

    <visual>
      <origin xyz="0 0 ${base_height/2}" rpy="0 0 0"/>
      <geometry>
        <box size="${base_width} ${base_length} ${base_height}"/>
      </geometry>
      <material name="orange"/>
    </visual>

    <inertial>
      <origin xyz="0 0 0" rpy="0 0 0"/>
      <mass value="${base_mass}"/>
      <inertia ixx="${base_mass / 12.0 * (base_length*base_length + base_height*base_height)}" ixy="0.0" ixz="0.0" iyy="${base_mass / 12.0 * (base_height*base_height + base_width*base_width)}" iyz="0.0" izz="${base_mass / 12.0 * (base_width*base_width + base_length*base_length)}"/>
      </inertial>
    </link>

    <joint name="${prefix}left_wheel_joint" type="continuous">
      <parent link="${prefix}base_link"/>
      <child link="${prefix}left_wheel"/>
      <origin xyz="0 -${base_width/2} ${z_offset}" rpy="0 0 0"/>
      <axis xyz="0 1 0"/>
      <dynamics damping="0.2"/>
    </joint>

    <!-- left wheel Link -->
    <link name="${prefix}left_wheel">
      <collision>
        <origin xyz="0 0 0" rpy="${PI/2} 0 0"/>
        <geometry>
          <cylinder length="${wheel_len}" radius="${wheel_radius}"/>
        </geometry>
      </collision>

      <visual>
        <origin xyz="0 0 0" rpy="${PI/2} 0 0"/>
        <geometry>
          <cylinder length="${wheel_len}" radius="${wheel_radius}"/>
        </geometry>
        <material name="black"/>
      </visual>

      <inertial>
        <origin xyz="0 0 0" rpy="${PI/2} 0 0"/>
        <mass value="${wheel_mass}"/>
        <inertia ixx="${wheel_mass / 12.0 * (3*wheel_radius + wheel_len*wheel_len)}" ixy="0.0" ixz="0.0" iyy="${wheel_mass / 12.0 * wheel_radius*wheel_radius}" iyz="0.0" izz="${wheel_mass / 12.0 * wheel_radius*wheel_radius}"/>
        </inertial>
      </link>

    <joint name="${prefix}right_wheel_joint" type="continuous">
      <parent link="${prefix}base_link"/>
      <child link="${prefix}right_wheel"/>
      <origin xyz="0 ${base_width/2} ${z_offset}" rpy="0 0 0"/>
      <axis xyz="0 1 0"/>
      <dynamics damping="0.2"/>
    </joint>

    <!-- right wheel Link -->
    <link name="${prefix}right_wheel">
      <collision>
        <origin xyz="0 0 0" rpy="${PI/2} 0 0"/>
        <geometry>
          <cylinder length="${wheel_len}" radius="${wheel_radius}"/>
        </geometry>
      </collision>

      <visual>
        <origin xyz="0 0 0" rpy="${PI/2} 0 0"/>
        <geometry>
          <cylinder length="${wheel_len}" radius="${wheel_radius}"/>
        </geometry>
        <material name="black"/>
      </visual>

      <inertial>
        <origin xyz="0 0 0" rpy="${PI/2} 0 0"/>
        <mass value="${wheel_mass}"/>
        <inertia ixx="${wheel_mass / 12.0 * (3*wheel_radius + wheel_len*wheel_len)}" ixy="0.0" ixz="0.0" iyy="${wheel_mass / 12.0 * wheel_radius*wheel_radius}" iyz="0.0" izz="${wheel_mass / 12.0 * wheel_radius*wheel_radius}"/>
        </inertial>
      </link>

    <joint name="${prefix}caster_frontal_wheel_joint" type="fixed">
      <parent link="${prefix}base_link"/>
      <child link="${prefix}caster_frontal_wheel"/>
      <origin xyz="${base_width/2 - caster_wheel_radius} 0 ${z_offset}" rpy="0 0 0"/>
    </joint>

    <!-- caster frontal wheel Link -->
    <link name="${prefix}caster_frontal_wheel">
      <collision>
        <origin xyz="0 0 0" rpy="0 0 0"/>
        <geometry>
          <sphere radius="${caster_wheel_radius}"/>
        </geometry>
      </collision>

      <visual>
        <origin xyz="0 0 0" rpy="0 0 0"/>
        <geometry>
          <sphere radius="${caster_wheel_radius}"/>
        </geometry>
        <material name="white"/>
      </visual>

      <inertial>
        <origin xyz="0 0 0" rpy="0 0 0"/>
        <mass value="${caster_wheel_mass}"/>
        <inertia ixx="${caster_wheel_mass * 0.4 * (caster_wheel_radius * caster_wheel_radius)}" ixy="0.0" ixz="0.0" iyy="${caster_wheel_mass * 0.4 * (caster_wheel_radius * caster_wheel_radius)}" iyz="0.0" izz="${caster_wheel_mass * 0.4 * (caster_wheel_radius * caster_wheel_radius)}"/>
        </inertial>
      </link>

    <joint name="${prefix}caster_rear_wheel_joint" type="fixed">
      <parent link="${prefix}base_link"/>
      <child link="${prefix}caster_rear_wheel"/>
      <origin xyz="${-base_width/2 + caster_wheel_radius} 0 ${z_offset}" rpy="0 0 0"/>
    </joint>

    <!-- caster rear wheel Link -->
    <link name="${prefix}caster_rear_wheel">
      <collision>
        <origin xyz="0 0 0" rpy="0 0 0"/>
        <geometry>
          <sphere radius="${caster_wheel_radius}"/>
        </geometry>
      </collision>

      <visual>
        <origin xyz="0 0 0" rpy="0 0 0"/>
        <geometry>
          <sphere radius="${caster_wheel_radius}"/>
        </geometry>
        <material name="white"/>
      </visual>

      <inertial>
        <origin xyz="0 0 0" rpy="0 0 0"/>
        <mass value="${caster_wheel_mass}"/>
        <inertia ixx="${caster_wheel_mass * 0.4 * (caster_wheel_radius * caster_wheel_radius)}" ixy="0.0" ixz="0.0" iyy="${caster_wheel_mass * 0.4 * (caster_wheel_radius * caster_wheel_radius)}" iyz="0.0" izz="${caster_wheel_mass * 0.4 * (caster_wheel_radius * caster_wheel_radius)}"/>
        </inertial>
      </link>

  </xacro:macro>

</robot>

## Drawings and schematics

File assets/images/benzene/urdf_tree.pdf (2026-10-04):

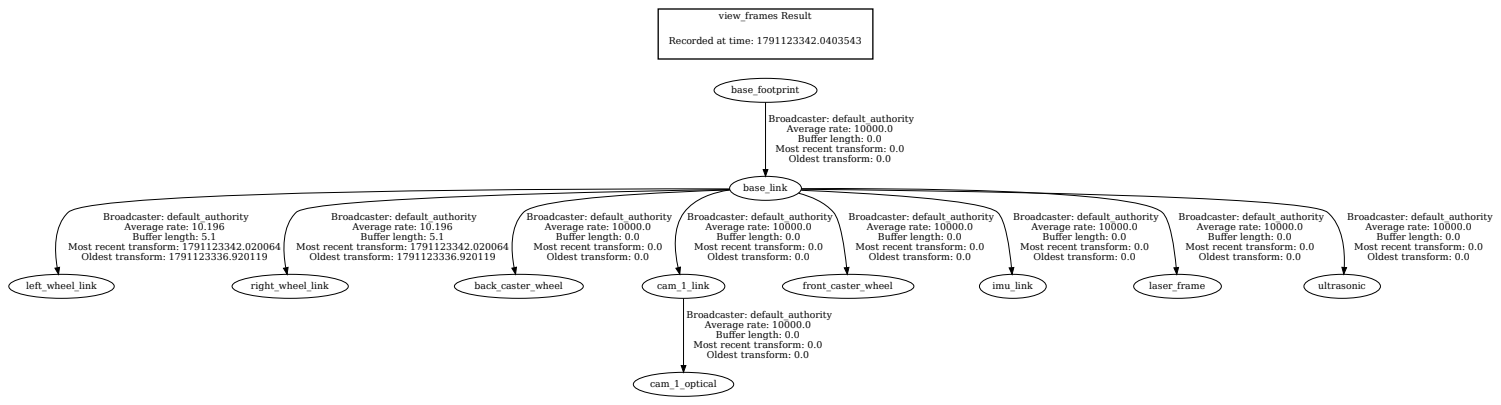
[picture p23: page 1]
view_frames Result; base_link; left_wheel_link; Broadcaster: default_authority Average rate: 10.196 Buffer length: 5.1; right_wheel_link; back_caster_wheel; cam_1_link; front_caster_wheel; imu_link; laser_frame; ultrasonic; base_footprint; cam_1_optical

Recorded at time: 1791123342.0403543

Broadcaster: default_authority
Average rate: 10000.0
Buffer length: 0.0
Most recent transform: 0.0
Oldest transform: 0.0

Most recent transform: 1791123342.020064
Oldest transform: 1791123336.920119

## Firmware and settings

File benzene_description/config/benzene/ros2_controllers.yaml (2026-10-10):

controller_manager:
  ros__parameters:
    update_rate: 20 # Hz

    diff_drive_controller:
      type: diff_drive_controller/DiffDriveController

    joint_state_broadcaster:
      type: joint_state_broadcaster/JointStateBroadcaster

diff_drive_controller:
  ros__parameters:

    pose_covariance_diagonal:  [0.001, 0.001, 0.0, 0.0, 0.0, 0.02]
    twist_covariance_diagonal: [0.001, 0.0,   0.0, 0.0, 0.0, 0.02]

    publish_rate: 50.0
    left_wheel_names: ['left_wheel_joint']
    right_wheel_names: ['right_wheel_joint']
    wheels_per_side: 1
    wheel_separation: 0.185
    wheel_radius: 0.035
    odom_frame_id: odom
    base_frame_id: base_footprint
    enable_odom_tf: true
    use_stamped_vel: false

    linear.x.has_velocity_limits: false
    linear.x.has_acceleration_limits: false
    linear.x.has_jerk_limits: false
    linear.x.max_velocity: 0.0
    linear.x.min_velocity: 0.0
    linear.x.max_acceleration: 0.0
    linear.x.min_acceleration: 0.0
    linear.x.max_jerk: 0.0
    linear.x.min_jerk: 0.0

    angular.z.has_velocity_limits: false
    angular.z.has_acceleration_limits: false
    angular.z.has_jerk_limits: false
    angular.z.max_velocity: 0.0
    angular.z.min_velocity: 0.0
    angular.z.max_acceleration: 0.0
    angular.z.min_acceleration: 0.0
    angular.z.max_jerk: 0.0
    angular.z.min_jerk: 0.0

# Commented out as no parameters are passed to this controller:
#
# joint_state_broadcaster:
#   ros__parameters:

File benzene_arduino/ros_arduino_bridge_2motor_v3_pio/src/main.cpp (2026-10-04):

/*********************************************************************
 *  ROSArduinoBridge
 
    A set of simple serial commands to control a differential drive
    robot and receive back sensor and odometry data.

    Ported to PlatformIO / Arduino Nano from
    https://github.com/joshnewans/ros_arduino_bridge
    (itself a fork of hbrobotics/ros_arduino_bridge).
    Hardware: L298N (EN = PWM) + two quadrature encoders on D2/D3, A4/A5.
    See include/config.h, motor_driver.h and encoder_driver.h.

    Created for the Pi Robot Project: http://www.pirobot.org
    and the Home Brew Robotics Club (HBRC): http://hbrobotics.org
    
    Authors: Patrick Goebel, James Nugen

    Inspired and modeled after the ArbotiX driver by Michael Ferguson
    
    Software License Agreement (BSD License)

    Copyright (c) 2012, Patrick Goebel.
    All rights reserved.

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
    THIS SOFTWARE IS PROVIDED BY THE COPYRIGHT HOLDERS AND CONTRIBUTORS
    "AS IS" AND ANY EXPRESS OR IMPLIED WARRANTIES, INCLUDING, BUT NOT
    LIMITED TO, THE IMPLIED WARRANTIES OF MERCHANTABILITY AND FITNESS
    FOR A PARTICULAR PURPOSE ARE DISCLAIMED. IN NO EVENT SHALL THE
    COPYRIGHT OWNER OR CONTRIBUTORS BE LIABLE FOR ANY DIRECT, INDIRECT,
    INCIDENTAL, SPECIAL, EXEMPLARY, OR CONSEQUENTIAL DAMAGES (INCLUDING,
    BUT NOT LIMITED TO, PROCUREMENT OF SUBSTITUTE GOODS OR SERVICES;
    LOSS OF USE, DATA, OR PROFITS; OR BUSINESS INTERRUPTION) HOWEVER
    CAUSED AND ON ANY THEORY OF LIABILITY, WHETHER IN CONTRACT, STRICT
    LIABILITY, OR TORT (INCLUDING NEGLIGENCE OR OTHERWISE) ARISING IN
    ANY WAY OUT OF THE USE OF THIS SOFTWARE, EVEN IF ADVISED OF THE
 *  POSSIBILITY OF SUCH DAMAGE.
 *********************************************************************/

#include <Arduino.h>

/* Build configuration (USE_BASE, driver selection, BAUDRATE, MAX_PWM ...) */
#include "config.h"

/* Include definition of serial commands */
#include "commands.h"

/* Sensor functions */
#include "sensors.h"

#ifdef USE_BASE
  /* Motor driver function definitions */
  #include "motor_driver.h"

  /* Encoder driver function definitions */
  #include "encoder_driver.h"

  /* PID parameters and functions */
  #include "diff_controller.h"

  /* Convert the rate into an interval */
  const int PID_INTERVAL = 1000 / PID_RATE;
  
  /* Track the next time we make a PID calculation */
  unsigned long nextPID = PID_INTERVAL;

  /* Time of the last movement command, for the auto-stop */
  unsigned long lastMotorCommand = 0;
#endif

/* Variable initialization */

// A pair of variables to help parse serial commands (thanks Fergs)
int arg = 0;
int argIndex = 0;

// Variable to hold an input character
char chr;

// Variable to hold the current single-character command
char cmd;

// Character arrays to hold the first and second arguments
char argv1[16];
char argv2[16];

// The arguments converted to integers
long arg1;
long arg2;

/* Clear the current command parameters */
void resetCommand() {
  cmd = 0;
  memset(argv1, 0, sizeof(argv1));
  memset(argv2, 0, sizeof(argv2));
  arg1 = 0;
  arg2 = 0;
  arg = 0;
  argIndex = 0;
}

/* Run a command.  Commands are defined in commands.h */
void runCommand() {
  int i = 0;
  char *p = argv1;
  char *str;
  int pid_args[4];
  arg1 = atoi(argv1);
  arg2 = atoi(argv2);
  
  switch(cmd) {
  case GET_BAUDRATE:
    Serial.println(BAUDRATE);
    break;
  case ANALOG_READ:
    Serial.println(analogRead(arg1));
    break;
  case DIGITAL_READ:
    Serial.println(digitalRead(arg1));
    break;
  case ANALOG_WRITE:
    analogWrite(arg1, arg2);
    Serial.println("OK"); 
    break;
  case DIGITAL_WRITE:
    if (arg2 == 0) digitalWrite(arg1, LOW);
    else if (arg2 == 1) digitalWrite(arg1, HIGH);
    Serial.println("OK"); 
    break;
  case PIN_MODE:
    if (arg2 == 0) pinMode(arg1, INPUT);
    else if (arg2 == 1) pinMode(arg1, OUTPUT);
    Serial.println("OK");
    break;
  case PING:
    Serial.println(Ping(arg1));
    break;
    
#ifdef USE_BASE
  case READ_ENCODERS:
    Serial.print(readEncoder(LEFT));
    Serial.print(" ");
    Serial.println(readEncoder(RIGHT));
    break;
  case RESET_ENCODERS:
    resetEncoders();
    resetPID();
    Serial.println("OK");
    break;
  case MOTOR_SPEEDS:
    /* Reset the auto stop timer */
    lastMotorCommand = millis();
    if (arg1 == 0 && arg2 == 0) {
      setMotorSpeeds(0, 0);
      resetPID();
      moving = 0;
    }
    else moving = 1;
    leftPID.TargetTicksPerFrame = arg1;
    rightPID.TargetTicksPerFrame = arg2;
    Serial.println("OK"); 
    break;
  case MOTOR_RAW_PWM:
    /* Reset the auto stop timer */
    lastMotorCommand = millis();
    resetPID();
    moving = 0; // Sneaky way to temporarily disable the PID
    setMotorSpeeds(arg1, arg2);
    Serial.println("OK"); 
    break;
  case UPDATE_PID:
    /* u Kp:Kd:Ki:Ko  (only applied if all four values are present) */
    while (i < 4 && (str = strtok_r(p, ":", &p)) != nullptr) {
      pid_args[i] = atoi(str);
      i++;
    }
    if (i == 4 && pid_args[3] != 0) {   // Ko is a divisor, must not be 0
      Kp = pid_args[0];
      Kd = pid_args[1];
      Ki = pid_args[2];
      Ko = pid_args[3];
      Serial.println("OK");
    } else {
      Serial.println("Invalid Command");
    }
    break;
#endif
  default:
    Serial.println("Invalid Command");
    break;
  }
}

/* Setup function--runs once at startup. */
void setup() {
  Serial.begin(BAUDRATE);

// Initialize the motor controller and encoders
#ifdef USE_BASE
  initEncoders();
  initMotorController();
  resetPID();
#endif
}

/* Enter the main loop.  Read and parse input from the serial port
   and run any valid commands. Run a PID calculation at the target
   interval and check for auto-stop conditions.
*/
void loop() {
  while (Serial.available() > 0) {
    
    // Read the next character
    chr = Serial.read();

    // Terminate a command with a CR
    if (chr == 13) {
      if (arg == 1) argv1[argIndex] = 0;
      else if (arg == 2) argv2[argIndex] = 0;
      runCommand();
      resetCommand();
    }
    // Use spaces to delimit parts of the command
    else if (chr == ' ') {
      // Step through the arguments
      if (arg == 0) arg = 1;
      else if (arg == 1)  {
        argv1[argIndex] = 0;
        arg = 2;
        argIndex = 0;
      }
      continue;
    }
    else {
      if (arg == 0) {
        // The first arg is the single-letter command
        cmd = chr;
      }
      else if (arg == 1) {
        // Subsequent arguments can be more than one character
        if (argIndex < (int)sizeof(argv1) - 1) argv1[argIndex++] = chr;
      }
      else if (arg == 2) {
        if (argIndex < (int)sizeof(argv2) - 1) argv2[argIndex++] = chr;
      }
    }
  }
  
// If we are using base control, run a PID calculation at the appropriate intervals
#ifdef USE_BASE
  if (millis() > nextPID) {
    updatePID();
    nextPID += PID_INTERVAL;
  }
  
  // Check to see if we have exceeded the auto-stop interval
  if ((millis() - lastMotorCommand) > AUTO_STOP_INTERVAL) {
    setMotorSpeeds(0, 0);
    moving = 0;
  }
#endif
}

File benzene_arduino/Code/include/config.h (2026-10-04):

#pragma once
// ---------------------------------------------------------------------------
// config.h  -  every tunable number and pin for the benzene Uno firmware.
// If you only want to retune or rewire, this is the only file you touch.
// ---------------------------------------------------------------------------
#include <Arduino.h>

namespace cfg {

// ----- serial / timing -----
constexpr uint32_t BAUD              = 115200;
constexpr uint32_t CONTROL_PERIOD_US = 20000;   // 50 Hz: PID + telemetry
constexpr uint32_t CMD_TIMEOUT_MS    = 500;     // binary host: no command this long -> stop
constexpr uint32_t TEXT_CMD_TIMEOUT_MS = 2000;  // typed serial commands: longer, you are typing by hand
constexpr int16_t  MAX_TPS           = 3000;    // clamp on commanded ticks/s

// ----- direction fixes (flip if a wheel counts / spins backwards) -----
constexpr int8_t ENC_L_SIGN     = 1;
constexpr int8_t ENC_R_SIGN     = 1;
constexpr bool   MOTOR_L_INVERT = false;
constexpr bool   MOTOR_R_INVERT = false;

// ----- L298N pins: SAME as the ros_arduino_bridge reference (known to run on this wiring) -----
// Style used here: PWM on the IN pins, the two EN pins are simply held HIGH.
// These must be PWM-capable pins (3, 5, 6, 9, 10, 11).
constexpr bool    PWM_ON_INPUTS = true;
constexpr uint8_t L_FWD = 10, L_BWD = 6, L_EN = 13;
constexpr uint8_t R_FWD = 9,  R_BWD = 5, R_EN = 12;
// Alternative (the first wiring diagram): PWM on ENA/ENB, plain direction on IN1..IN4:
//   PWM_ON_INPUTS = false;  L_EN = 5, L_FWD = 11, L_BWD = 10;  R_EN = 6, R_FWD = 8, R_BWD = 9;
// In that mode ENA/ENB carry the PWM, so the ENA/ENB jumper caps MUST be removed.
// The Uno does not touch ANY motor pin until the first non-zero motor command.

// ----- encoder pins: also the same as the reference -----
// Fixed by encoders.cpp (pin-change interrupts, one ISR per wheel):
//   Left  : A = D2, B = D3   (PORTD, PCINT2)
//   Right : A = A4, B = A5   (PORTC, PCINT1)
// Changing these means editing encoders.cpp too.
// A4/A5 are the Uno's I2C pins; fine, because the IMU lives on the Pi.

// ----- PID starting values: TUNE THESE (live via SET_PID message) -----
constexpr float KP  = 0.10f;
constexpr float KI  = 0.50f;
constexpr float KD  = 0.00f;
constexpr float KFF = 0.10f;   // feedforward: PWM counts per (tick/s)
constexpr float VEL_FILTER_ALPHA = 0.5f;   // 1.0 = no smoothing
constexpr int   PWM_MIN = 0;   // smallest PWM that moves a wheel (0 = off)

}  // namespace cfg

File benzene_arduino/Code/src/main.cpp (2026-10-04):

// main.cpp - wiring only: init the modules, run the 50 Hz control loop.
#include <Arduino.h>
#include "config.h"
#include "console.h"
#include "encoders.h"
#include "motors.h"
#include "pid.h"
#include "protocol.h"

namespace {

Gains           g_gains{cfg::KP, cfg::KI, cfg::KD, cfg::KFF};
WheelController g_left, g_right;

uint32_t g_lastCmdMs = 0;
uint32_t g_timeoutMs = cfg::CMD_TIMEOUT_MS;
bool     g_watchdogTripped = true;   // stays tripped until the first command
bool     g_openLoop = false;         // true: 'o' command drives raw PWM, PID bypassed
int      g_pwmL = 0, g_pwmR = 0;
uint32_t g_lastLoopUs = 0;

float clampTps(int16_t v) {
  if (v > cfg::MAX_TPS)  return cfg::MAX_TPS;
  if (v < -cfg::MAX_TPS) return -cfg::MAX_TPS;
  return v;
}

void feedWatchdog(uint32_t timeoutMs) {
  g_timeoutMs = timeoutMs;
  g_lastCmdMs = millis();
  g_watchdogTripped = false;
}

void applyTargets(int16_t l, int16_t r, uint32_t timeoutMs) {
  g_openLoop = false;
  g_left.setTarget(clampTps(l));
  g_right.setTarget(clampTps(r));
  feedWatchdog(timeoutMs);
}

void resetEncoders() {
  encoders::reset();
  g_left.resetTicks(0);
  g_right.resetTicks(0);
}

void setGains(float kp, float ki, float kd, float kff) {
  g_gains.kp = kp;
  g_gains.ki = ki;
  g_gains.kd = kd;
  if (kff >= 0) g_gains.kff = kff;
  g_left.resetIntegrator();
  g_right.resetIntegrator();
}

// ----- binary protocol callbacks -----
void onCmdVel(int16_t l, int16_t r) { applyTargets(l, r, cfg::CMD_TIMEOUT_MS); }
void onSetPid(float kp, float ki, float kd) { setGains(kp, ki, kd, -1.0f); }

// ----- typed console callbacks -----
void textSetSpeed(int16_t l, int16_t r) { applyTargets(l, r, cfg::TEXT_CMD_TIMEOUT_MS); }

void textSetPwm(int16_t l, int16_t r) {
  g_openLoop = true;
  g_pwmL = l;
  g_pwmR = r;
  g_left.setTarget(0);
  g_right.setTarget(0);
  feedWatchdog(cfg::TEXT_CMD_TIMEOUT_MS);
}

void textGetVelocity(int16_t &l, int16_t &r) {
  l = (int16_t)g_left.velocity();
  r = (int16_t)g_right.velocity();
}

}  // namespace

void setup() {
  protocol::init({onCmdVel, resetEncoders, onSetPid, console::handleLine});
  console::init({textSetSpeed, textSetPwm, resetEncoders, setGains, textGetVelocity});
  encoders::init();
  motors::init();
  g_lastLoopUs = micros();
  Serial.println(F("benzene boot"));   // if you see this mid-session, the Uno RESET (power/USB glitch)
}

void loop() {
  protocol::poll();

  uint32_t nowUs = micros();
  if ((uint32_t)(nowUs - g_lastLoopUs) < cfg::CONTROL_PERIOD_US) return;
  float dt = (nowUs - g_lastLoopUs) * 1e-6f;
  g_lastLoopUs = nowUs;

  // watchdog: nobody told us what to do recently -> stop
  if (!g_watchdogTripped && (millis() - g_lastCmdMs) > g_timeoutMs) {
    g_watchdogTripped = true;
    g_openLoop = false;
    g_left.setTarget(0);
    g_right.setTarget(0);
  }

  int32_t tl, tr;
  encoders::snapshot(tl, tr);
  int pwmL = g_left.update(tl, dt, g_gains);    // always runs: keeps velocity estimate alive
  int pwmR = g_right.update(tr, dt, g_gains);
  if (g_openLoop) {
    pwmL = g_pwmL;
    pwmR = g_pwmR;
  }
  motors::set(Side::Left,  pwmL);
  motors::set(Side::Right, pwmR);

  if (protocol::streaming()) {
    protocol::StateMsg s;
    s.stamp_us = nowUs;
    s.ticks_l  = tl;
    s.ticks_r  = tr;
    s.vel_l    = (int16_t)g_left.velocity();
    s.vel_r    = (int16_t)g_right.velocity();
    s.flags    = g_watchdogTripped ? protocol::FLAG_WATCHDOG : 0;
    protocol::sendState(s);
  }
}

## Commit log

2026-08-12 Started with sim with old stl need to update the new ones
    [camera.stl, chassis.stl, lidar.stl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]
2026-08-13 Fix those urdf.xacros
    [base.urdf.xacro, benzene.urdf.xacro, camera.urdf.xacro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]
2026-08-15 added robot visual urdf need to add c0ollison and inertial prop
    [base.urdf.xacro, benzene.urdf.xacro, inertial_macros.xacro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]
2026-08-16 added robot collision and intertial prop
    [base.urdf.xacro, benzene.urdf.xacro, wheel.urdf.xacro]
2026-08-16 Added gazebo and other dir, need to work on ros2 controller side
    [cafe_counter.obj, counter_no_sink.obj, counter_sink.obj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]
2026-08-16 Done with the ros2 control to operate in gz all works in sim, run using bash script will update readme in future to control the benzene
    [benzene.urdf.xacro, benzene_control.urdf.xacro, benzene_controllers.yaml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]
2026-08-16 Added some demo actions
    [ros2_controllers.yaml, ros2_controllers_template.yaml]
2026-08-18 Imu sensor fusion is working, problems faced are : dislocation of model in rviz while launching nav script, rqt_graph is messed up
    [ros2_controllers.yaml]
2026-08-26 added arduino test code,problems faced are : dislocation of model in rviz while launching nav script, rqt_graph is messed up
    [ros2_controllers.yaml]
2026-08-26 Need to fix rviz shift can't go ahead with that slam fails
    [ros2_controllers.yaml]
2026-08-28 Added test scripts to navigation, also added camera to work with
    [benzene.urdf.xacro, camera.urdf.xacro, ros2_controllers.yaml]
2026-08-28 Added april tag based docking
    [ros2_controllers.yaml]
2026-08-28 Camera detection for the april tag is done
2026-08-29 Squashed 'benzene_hardware/' content from commit e5eddd2
    git-subtree-dir: benzene_hardware
    git-subtree-split: e5eddd2982f4eda21a88835f98bb2ea59e59ab6a
    [diffbot.materials.xacro, diffbot.ros2_control.xacro, diffbot.urdf.xacro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]
2026-08-30 Made some hardware interface changes to test on real bot, yet to test on real bot: test new benzene robot launch file
    [benzene_control.urdf.xacro, ros2_controllers.yaml]
2026-08-30 Added launch code for lidar camera and joystick, also made robot code similar to gazebo code yet to test with the harrdware
2026-08-30 Added warehouse.sdf world also tested it works
    [ros2_controllers.yaml, warehouse.sdf]
2026-09-03 Added some new test cmds
    [warehouse.sdf]
2026-09-04 Added new wheel sepration also updated joy for robot
    [ros2_controllers.yaml, ros2_controllers_template.yaml]
2026-09-04 Added imu pkg, yet to test
2026-09-06 Made .sh code easy to lauch to switch world file better for ease
2026-09-06 Added the code that is been used on the arduino side
2026-09-07 Solved issue of reassing port of arduino and lidar
    [benzene_control.urdf.xacro, ros2_controllers.yaml]
2026-09-07 Added keyboard, fixed file issues for imu
2026-09-08 Testing imu in main robot launch code, working on new model urdf
    [base_link.stl, camera_link.stl, caster_link.stl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]
2026-09-11 Added benzene new urdf matching to the real robot
    [benzene.urdf.xacro, benzene_control.urdf.xacro, camera.stl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]
2026-09-11 Made URDF clean
    [base.xacro, benzene.urdf.xacro, caster.xacro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]
2026-09-12 added switch between worlds for gazebo.sh too, made cleaner .sh files, removed all depth cam related code from nav urdf cam gz bridge nav rviz. adjusted april tag in cafe world
    [benzene.urdf.xacro, simple_camera.xacro]
2026-09-13 Fixed the lidar scan drift
    [benzene_controllers.yaml, diffbot_controllers.yaml, diffbot_description.urdf.xacro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]
2026-09-14 Added new maps they work still tunning needs seeing initial drift issue again
    [conference_table.stl, door.stl, floor_1.obj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]
2026-09-20 Updated task1a code meeting required coding standards
    [ROB_long_table.stl, ROB_office.stl, ROB_work_station.stl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]
2026-09-21 Started with dagger imitation learning
    [race2.sdf, ros2_controllers.yaml]
2026-09-21 Added marker for lidar visualize in rviz
    [race2.sdf]
2026-09-23 Removed comments from the cmakes
    [ros2_controllers.yaml]
2026-09-25 updated rviz for the full screen view, add new files to dagger now can detect the line mark them based on how far they are. updated the rac2 world removed the start green patch, need to work on insta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
    [race2.sdf, ros2_controllers_template.yaml]
2026-09-26 Update cmkaes and pkg xml for the coding standards also fixed all the build time warnings
    [diffbot_system.cpp, diffbot_system.hpp]
2026-10-04 ros-arduino-bridge-2mootr-v3 is working to pid tune, need to look if it works with the current hardware interface
2026-10-04 Updated cnts also some work in hardware interface
    [benzene_control.urdf.xacro, diffbot.ros2_control.xacro, diffbot.urdf.xacro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]
2026-10-04 Added and updated ultrasonic in the gazebo, yet to add in the navigation code
    [benzene.urdf.xacro, ultrasonic_sensor.xacro]
2026-10-04 Updated requirement.sh file also maintained all in assests added laser cut files
    [cross.dxf, lower.dxf, middle1.dxf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]
2026-10-05 PID to test
    [diffbot.ros2_control.xacro]
2026-10-07 Added ultrasonic sensor
2026-10-07 Ultrasonic works
2026-10-07 Fixed the shift of ultrasonic sensor for the sim also updated params to match the real us
    [ultrasonic_sensor.xacro]
2026-10-09 Changed real bot working
    [diffbot.ros2_control.xacro]
2026-10-09 circuit completed
2026-10-09 Added the CAD files
2026-10-10 Added slam for real bot
    [benzene.urdf.xacro]
2026-10-10 Pid tuned
    [benzene_control.urdf.xacro, ros2_controllers.yaml, ros2_controllers_template.yaml]
2026-10-17 Updated lidar code to reset itself on fialure
